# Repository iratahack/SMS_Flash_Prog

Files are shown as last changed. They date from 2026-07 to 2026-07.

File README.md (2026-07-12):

# SEGA Master System Flash Cartridge Programmer

A small USB/Arduino-based programmer and diagnostic tool for Sega Master System ROM cartridges.
It provides a serial-menu interface to identify the cartridge flash, erase and program NOR flash chips,
read or write individual bytes, perform blank checks, and transfer full ROM images using XMODEM-1K.
This repository contains the firmware source (AVR C) used on the programmer hardware and example
host-side workflows for sending/receiving ROM images.

## Hardware

The programmer is an ATmega328p (Arduino Uno / Nano) running at 16 MHz. It accesses the SMS
cartridge slot through the following bus signals:

- **Address bus (A0–A15)**: driven by two cascaded 74HC595 shift registers clocked over the ATmega's SPI peripheral (MOSI=PB3, SCK=PB5, SS=PB2). A high pulse on **RCLK** (PC0) latches the shifted address onto the cartridge bus.
- **Data bus (D0–D7)**: bidirectional GPIO on Arduino pins D2–D9 (PD2–PD7 and PB0–PB1). Direction is toggled per read/write.
- **Control signals**: `_CE` on PC1, `_RD` on PC2, `_WR` on PC3, `_RST` on PC4 (all active low).

KiCad design files for the programmer shield — including schematic, PCB, and Gerbers — live in
[`Arduino_SMS_Cart_Programmer/`](Arduino_SMS_Cart_Programmer/).

### Supported flash chips & Carts

The firmware auto-detects the flash device using the AMD/SST JEDEC ID command sequence and
currently recognises the SST39SF family:

| Manufacturer ID | Device ID | Part | Size  |
| --- | --- | --- | ----- |
| `0xBF` (SST) | `0xB5` | SST39SF010 | 128 KB |
| `0xBF` (SST) | `0xB6` | SST39SF020 | 256 KB |
| `0xBF` (SST) | `0xB7` | SST39SF040 | 512 KB |

The programmer has been tested with the flash cart by [ichigobankai](https://github.com/ichigobankai/SMS_PCB_SLOT1-2_2GAL_DIP)

### Supported mappers

The firmware auto-detects the cartridge mapper at boot and can be switched manually from the menu:

- **SEGA** — standard 16 KB-banked SEGA mapper (bank register at `0xFFFF`).
- **Iratahack** — 3-bit bank + 2-bit game slot (`0xFFFE` / `0xFFFF`) for multi-game carts.

## Building the firmware

Install the AVR toolchain:

```sh
sudo apt-get install gcc-avr avr-libc avrdude
```

Build from the `src/` directory:

```sh
cd src
make                    # compile -> SMSFlasher.bin
make SMSFlasher.bin.hex # Intel HEX output (flashable with avrdude)
make clean              # remove build artifacts
make dis                # disassembly via avr-objdump | less
```

A separate diagnostic firmware that exercises just the 74HC595 address-bus shift registers
lives in [`74hc595/`](74hc595/) and builds with its own `Makefile` in the same way.

Pre-built releases are published on the GitHub Releases page when a `release/vX.Y.Z` tag
is pushed; each release includes `SMSFlasher.bin` and `SMSFlasher.bin.hex`.

## Flashing the firmware to the Arduino

With the Arduino connected as `/dev/ttyUSB0`:

```sh
cd src
make download
```

This runs `avrdude -c arduino -p atmega328p -P /dev/ttyUSB0 -b 115200` against
`SMSFlasher.bin.hex`. Override the port/programmer by editing the `download` target
if your setup differs.

### Arduino COM port setup for WSL

After connecting the programmer via USB to a Windows machine, enter the command below in an
administrator PowerShell to attach the Arduino COM port from Windows to WSL:

```sh
usbipd list # look for USB-SERIAL CH340 (COM4) or similar
usbipd bind --busid <BUSIS> # as administrator
usbipd attach --wsl --busid <BUSID>
```

If the error below is displayed and you already have the latest install of WSL try
`sudo modprobe vhci_hcd` from WSL:

```
usbipd: info: Using WSL distribution 'Ubuntu-22.04' to attach; the device will be available in all WSL 2 distributions.
usbipd: error: WSL kernel is not USBIP capable; update with 'wsl --update'.
```

## Using the programmer

Remember to disconnect the USB connector (power) before connecting or disconnecting a Sega Master System cartridge to
avoid damaging the cartridge or the programmer. When connecting the cartridge, insert the cartridge into the connector
with the front of the cartridge facing the Arduino.

Once the firmware is running, connect a serial terminal to the device at **1,000,000 baud**,
8-N-1, no flow control. The UI uses ANSI colour and Unicode box-drawing characters, so
use a terminal that supports both (e.g. `picocom`, `minicom`). On Windows,
[ExtraPUTTY](https://sourceforge.net/projects/extraputty/) is a good choice and supports
XMODEM-1K for file transfer.

The firmware redraws a full-screen menu on each iteration:

| Key | Action |
| --- | --- |
| `1` | Erase flash (full-chip erase) |
| `2` | Blank check — scan entire flash for `0xFF` |
| `3` | Program flash (receive ROM image over XMODEM-1K) |
| `4` | Checksum — compute CRC32 of flash and compare against last programmed CRC32 |
| `5` | Read a single byte from a hex address |
| `6` | Program a single byte at a hex address |
| `7` | Read ROM — send full flash contents to host over XMODEM-1K |
| `8` | Display SDSC ROM header (if present) |
| `9` | Erase, program (XMODEM-1K), and verify in one step |
| `0` | Toggle between detected mappers (SEGA / Iratahack) |
| `s` | Change ROM/flash size |

The flash size used by operations `2`, `4`, `7`, and `9` is determined by the JEDEC ID
read at each menu redraw, so the programmer adapts automatically to whichever SST39SF
part is installed.

### Transferring ROM images over XMODEM

The firmware uses **XMODEM-1K** (1024-byte packets with CRC-16). The receive path also
accepts classic 128-byte XMODEM packets, but the send path always transmits 1K blocks.
ExtraPUTTY includes XMODEM-1K support for both sending and receiving.

## Repository layout

- [`src/`](src/) — programmer firmware (main target).
- [`74hc595/`](74hc595/) — standalone test firmware that cycles the address-bus shift registers.
- [`Arduino_SMS_Cart_Programmer/`](Arduino_SMS_Cart_Programmer/) — KiCad hardware design files.
- [`.github/workflows/build.yml`](.github/workflows/build.yml) — CI build and release workflow.

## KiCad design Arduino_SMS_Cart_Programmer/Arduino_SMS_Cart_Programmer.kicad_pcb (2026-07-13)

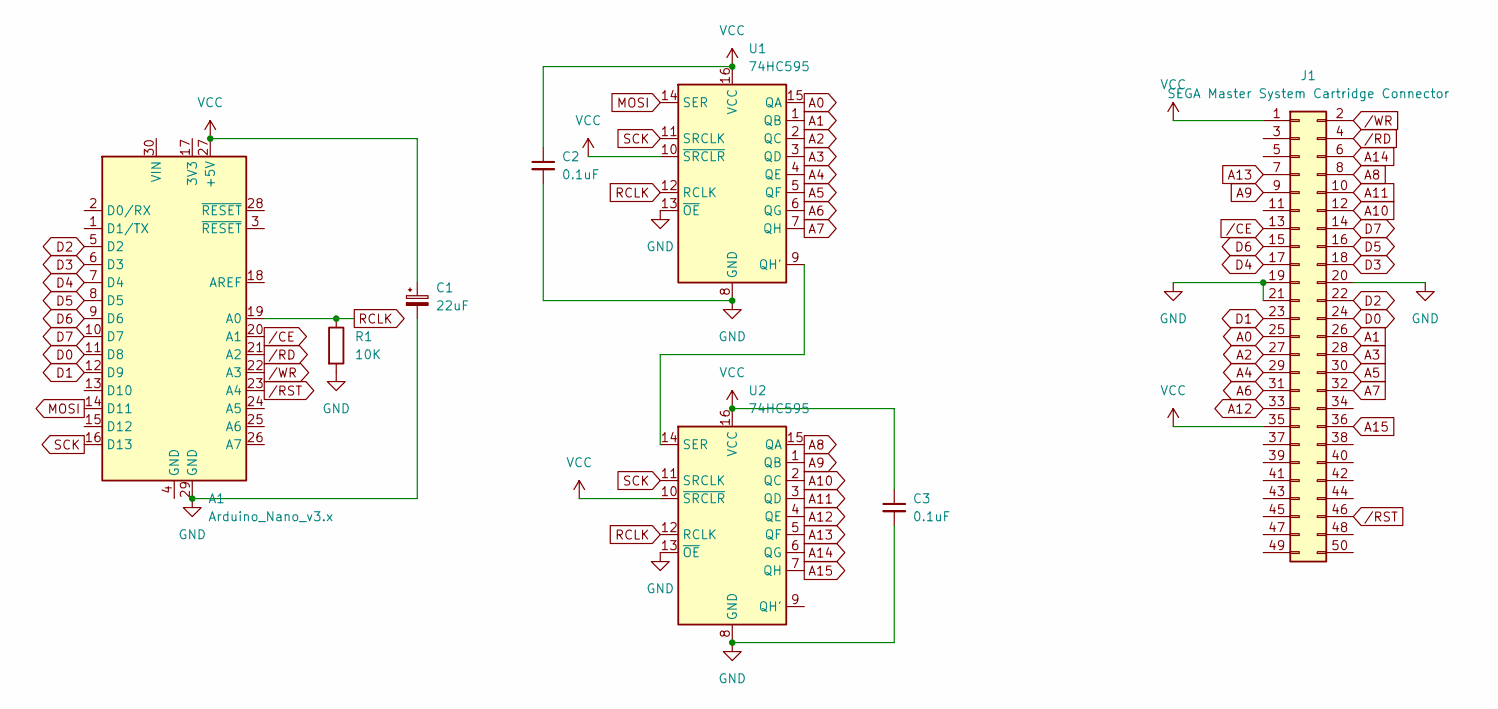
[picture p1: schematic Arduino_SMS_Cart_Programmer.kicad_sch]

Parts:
A1: Arduino_Nano_v3.x; Arduino_Nano
C1: 22uF; CP_Radial_D5.0mm_P2.00mm
C2, C3: 0.1uF; C_Disc_D4.3mm_W1.9mm_P5.00mm
J1: SEGA Master System Cartridge Connector; SEGA_Master_System_Cart_Connector
R1: 10K; R_Axial_DIN0204_L3.6mm_D1.6mm_P7.62mm_Horizontal
U1, U2: 74HC595; DIP-16_W7.62mm

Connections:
A0: J1.25, U1.15 (QA)
A1: J1.26, U1.1 (QB)
A2: J1.27, U1.2 (QC)
A3: J1.28, U1.3 (QD)
A4: J1.29, U1.4 (QE)
A5: J1.30, U1.5 (QF)
A6: J1.31, U1.6 (QG)
A7: J1.32, U1.7 (QH)
A8: J1.8, U2.15 (QA)
A9: J1.9, U2.1 (QB)
A10: J1.12, U2.2 (QC)
A11: J1.10, U2.3 (QD)
A12: J1.33, U2.4 (QE)
A13: J1.7, U2.5 (QF)
A14: J1.6, U2.6 (QG)
A15: J1.36, U2.7 (QH)
D0: A1.11 (D8), J1.24
D1: A1.12 (D9), J1.23
D2: A1.5 (D2), J1.22
D3: A1.6 (D3), J1.18
D4: A1.7 (D4), J1.17
D5: A1.8 (D5), J1.16
D6: A1.9 (D6), J1.15
D7: A1.10 (D7), J1.14
GND: A1.29 (GND), C1.2, C2.2, C3.2, J1.19, J1.20, J1.21, R1.2, U1.8 (GND), U1.13 (~OE), U2.8 (GND), U2.13 (~OE)
MOSI: A1.14 (D11), U1.14 (SER)
unnamed: U1.9 (QH'), U2.14 (SER)
RCLK: A1.19 (A0), R1.1, U1.12 (RCLK), U2.12 (RCLK)
SCK: A1.16 (D13), U1.11 (SRCLK), U2.11 (SRCLK)
VCC: A1.27 (+5V), C1.1, C2.1, C3.1, J1.1, J1.35, U1.10 (~SRCLR), U1.16 (VCC), U2.10 (~SRCLR), U2.16 (VCC)
/CE: A1.20 (A1), J1.13
/RD: A1.21 (A2), J1.4
/RST: A1.23 (A4), J1.46
/WR: A1.22 (A3), J1.2

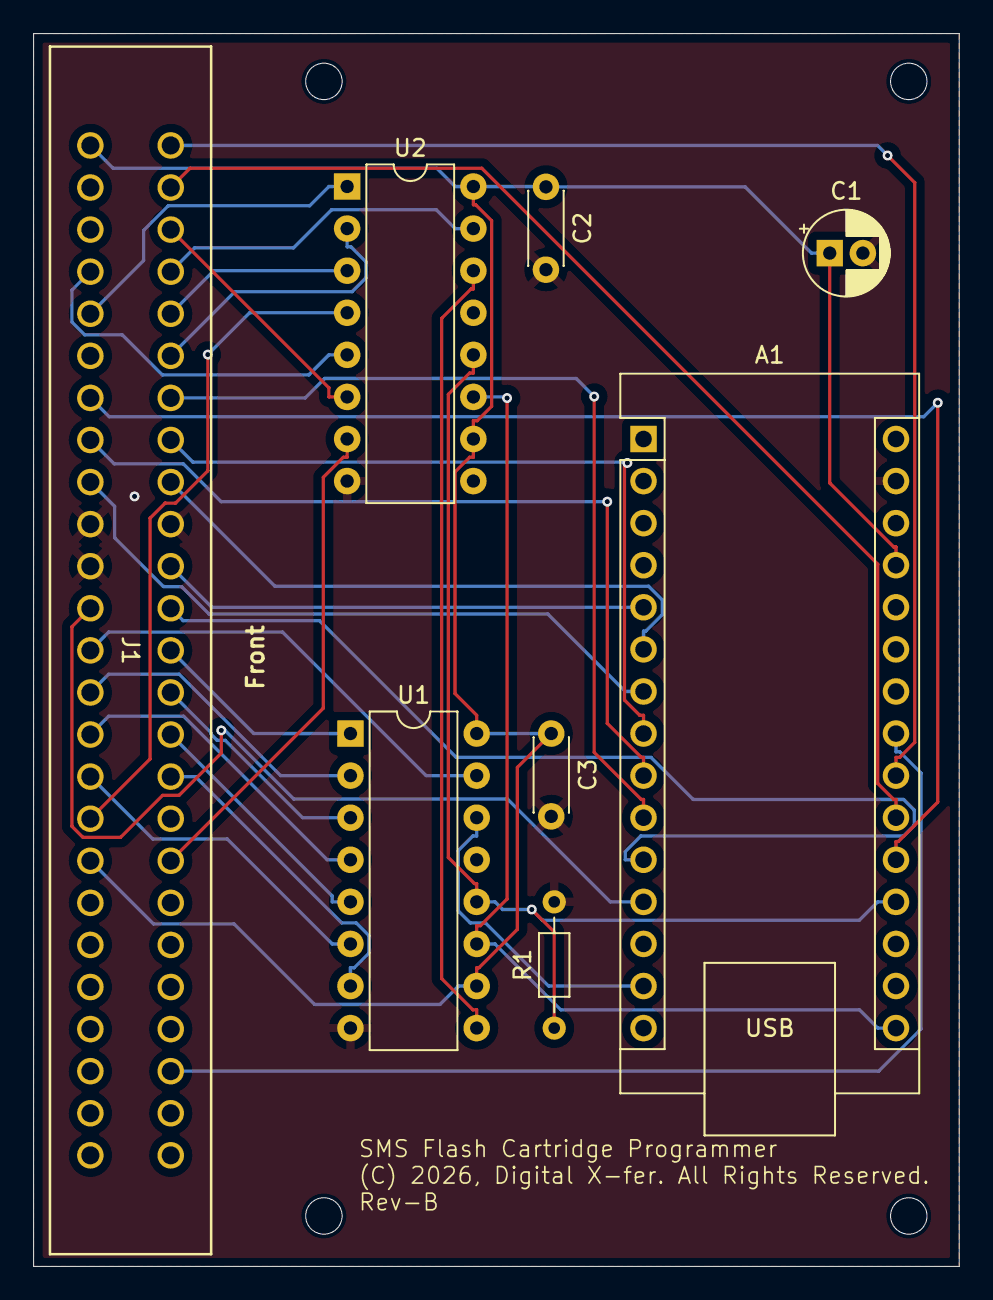
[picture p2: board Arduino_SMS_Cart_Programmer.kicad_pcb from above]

Board: 2 copper layers, 55.9 x 74.4 mm, 12 parts (0 on the bottom side), 34 nets.

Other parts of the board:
REF1, REF2, REF3, REF4: MountingHole_2.2mm_M2

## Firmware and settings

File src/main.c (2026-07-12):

#include <string.h>
#include <util/delay.h>
#include "common.h"
#include "mappers.h"

#define RCLK_PIN PC0
#define _CE_PIN PC1
#define _RD_PIN PC2
#define _WR_PIN PC3
#define _RST_PIN PC4

extern uint32_t XMODEM_ReceiveFile(uint8_t *pBuffer, void (*processBlock)(uint8_t *, uint16_t));
extern uint32_t XMODEM_SendFile(uint8_t *pBuffer, uint32_t length, void (*processBlock)(uint8_t *, uint32_t, uint16_t));
extern void initUART(void);
extern void initTimer(void);
extern void updateCRC32(uint32_t *crc, const uint8_t data);

// XMODEM receive buffer
static uint8_t buffer[1024];
// Address pointer for flash programming
static uint32_t flashAddress;
// Flash size in bytes
static uint32_t flashSize = 0;
// CRC32 of flash
static uint32_t flashCRC32;
// CRC32 of programmed data
static uint32_t progCRC32;
// Current mapper index
static uint8_t mapperIndex;
// Y position for text output
static uint8_t yPos;

/* Helpers to move cursor and clear */
void clear_screen(void)
{
    printf(CSI "2J" CSI "H");
    fflush(stdout);
}
void move_to(int r, int c)
{
    printf(CSI "%d;%dH", r, c);
    fflush(stdout);
}
void hide_cursor(void)
{
    printf(CSI "?25l");
    fflush(stdout);
}
void show_cursor(void)
{
    printf(CSI "?25h");
    fflush(stdout);
}

static void SPI_initMaster(void)
{
    // Set MOSI (PB3), SCK (PB5), SS (PB2) as output
    DDRB |= (_BV(PB3) | _BV(PB5) | _BV(PB2));
    // Set MISO (PB4) as input
    DDRB &= ~(_BV(PB4));

    // Enable SPI, Set as Master, Set clock rate fosc/4
    SPCR = _BV(SPE) | _BV(MSTR);
    // Double speed for fosc/2
    SPSR = _BV(SPI2X);
}

static void SPI_send(uint8_t data)
{
    SPDR = data; // Load data into the buffer
    while (!(SPSR & _BV(SPIF)))
        ; // Wait until transmission complete
}

static void disable_data_pins_pullups(void)
{
    // D2-D7: PD2-PD7
    PORTD &= ~(0b11111100); // Disable pull-ups on PD2-PD7
    // D8-D9: PB0-PB1
    PORTB &= ~(0b00000011); // Disable pull-ups on PB0, PB1
}

static void set_data_pins_output(void)
{
    // D2-D7: PD2-PD7 (6 bits)
    DDRD |= 0b11111100; // Set PD2-PD7 as output
    // D8-D9: PB0-PB1
    DDRB |= 0b00000011; // Set PB0, PB1 as output
}

static void set_data_pins_input(void)
{
    // D2-D7: PD2-PD7
    DDRD &= ~(0b11111100); // Set PD2-PD7 as input
    // D8-D9: PB0-PB1
    DDRB &= ~(0b00000011); // Set PB0, PB1 as input
    disable_data_pins_pullups();
}

/* Inline macro to read D2-D9 (PD2-PD7 and PB0-PB1). Keep the same
   name so existing call sites do not need to change. Wrap operands
   in parentheses to avoid surprises when expanded. */
#define read_data_pins() ((uint8_t)(((PIND) & 0b11111100) | ((PINB) & 0b00000011)))

// Send a 16-bit address via SPI to the shift registers
static void SPI_sendAddress(uint16_t address)
{
    SPI_send((address >> 8) & 0xFF); // Send high byte
    SPI_send(address & 0xFF);        // Send low byte
    PORTC |= _BV(RCLK_PIN);          // Set RCLK high
    PORTC &= ~_BV(RCLK_PIN);         // Set RCLK low
}

void writeCartByte(uint32_t address, uint8_t data)
{
    // Set data pins as output
    set_data_pins_output();

    // Send address
    SPI_sendAddress(address);

    // Write data to data pins
    PORTD = (PORTD & 0b00000011) | (data & 0b11111100); // D2-D7
    PORTB = (PORTB & 0b11111100) | (data & 0b00000011); // D8-D9

    // _CE low
    PORTC &= ~(_BV(_CE_PIN));

    // Pulse WR to write data, min delay is 40nS
    PORTC &= ~(_BV(_WR_PIN));
    PORTC |= _BV(_WR_PIN);

    // _CE high
    PORTC |= _BV(_CE_PIN);
}

uint8_t readRawCartByte(uint32_t address)
{
    uint8_t data;

    // Set data pins to input
    set_data_pins_input();

    // Send address
    SPI_sendAddress(address);
    // _CE low, _RD low
    PORTC &= ~(_BV(_CE_PIN) | _BV(_RD_PIN));

    // Read data from data pins
    // Add nop's to allow data to stabilize
    asm("nop\n"
        "nop\n");
    data = read_data_pins();

    // _CE high, _RD high
    PORTC |= _BV(_RD_PIN) | _BV(_CE_PIN);

    return data;
}

static uint8_t readCartByte(uint32_t address)
{
    uint8_t data;
    uint16_t offset;

    // Select bank/slot and compute offset
    translateAddress(address, &offset);

    // Set data pins to input
    set_data_pins_input();

    // Send address
    SPI_sendAddress(offset);
    // _CE low, _RD low
    PORTC &= ~(_BV(_CE_PIN) | _BV(_RD_PIN));

    // Read data from data pins
    // Add nop's to allow data to stabilize
    asm("nop\n"
        "nop\n");
    data = read_data_pins();

    // _CE high, _RD high
    PORTC |= _BV(_RD_PIN) | _BV(_CE_PIN);

    return data;
}

// Helper function to read a 16-bit pointer from header (file scope)
static uint16_t readHeaderPointer(uint16_t addr)
{
    return readCartByte(addr) | (readCartByte(addr + 1) << 8);
}

static uint8_t bcdToUint8(uint8_t bcd)
{
    return ((bcd >> 4) & 0x0F) * 10 + (bcd & 0x0F);
}

// Helper function to print a null-terminated string from ROM (file scope)
static void printROMString(uint16_t strPtr)
{
    if (strPtr == 0 || strPtr == 0xFFFF)
    {
        printf("(None)");
        return;
    }

    for (uint16_t i = strPtr;; i++)
    {
        uint8_t c = readCartByte(i);
        if (c == 0)
            break;
        if (c < 32)
            continue; // Skip control characters
        printf("%c", c);
    }
}

static uint16_t findSDSCHeader(void)
{
    // Search for SDSC signature in ROM
    // Common locations are 0x7FE0 and near the start of ROM
    const uint16_t searchLocations[] = {0x7FE0, 0x0000};
    const uint16_t searchRanges[] = {0x10, 0x100}; // How far to search from each location

    for (uint8_t loc = 0; loc < sizeof(searchLocations) / sizeof(searchLocations[0]); loc++)
    {
        uint16_t addr = searchLocations[loc];
        for (uint16_t i = 0; i < searchRanges[loc]; i++)
        {
            if (readCartByte(addr + i) == 'S' &&
                readCartByte(addr + i + 1) == 'D' &&
                readCartByte(addr + i + 2) == 'S' &&
                readCartByte(addr + i + 3) == 'C')
            {
                return addr + i;
            }
        }
    }
    return 0; // Return 0 if not found
}

static void displaySDSCHeader(void)
{
    uint16_t signature = findSDSCHeader();
    if (!signature)
    {
        printf(FG_RED "No SDSC ROM signature detected." COLOR_RESET "\n");
        return; // No SDSC header found
    }

    uint16_t headerAddr = signature + 4; // Skip "SDSC" signature
    uint8_t versionMajor = bcdToUint8(readCartByte(headerAddr + 0));
    uint8_t versionMinor = bcdToUint8(readCartByte(headerAddr + 1));

    printf("SDSC Header Information:\n");
    printf("Version: %u.%u\n", versionMajor, versionMinor);

    // Display release date from BCD format (DD MM YY YY)
    uint8_t day = bcdToUint8(readCartByte(headerAddr + 2));
    uint8_t month = bcdToUint8(readCartByte(headerAddr + 3));
    uint8_t yearLow = readCartByte(headerAddr + 4);
    uint8_t yearHigh = readCartByte(headerAddr + 5);

    uint16_t year = (((yearHigh >> 4) & 0x0F) * 1000) +
                    ((yearHigh & 0x0F) * 100) +
                    (((yearLow >> 4) & 0x0F) * 10) +
                    (yearLow & 0x0F);

    printf("Release Date: %04u.%02u.%02u\n", year, month, day);

    // Read all string pointers (they're stored sequentially)
    uint16_t authorPtr = readHeaderPointer(headerAddr + 6);
    uint16_t namePtr = readHeaderPointer(headerAddr + 8);
    uint16_t descPtr = readHeaderPointer(headerAddr + 10);

    // Display all strings using the same format
    printf("Author: ");
    printROMString(authorPtr);
    printf("\nName: ");
    printROMString(namePtr);
    printf("\nDescription: ");
    printROMString(descPtr);
    printf("\n");
}

static uint32_t displayROMHeader(void)
{
    uint32_t size = 0;
    // ROM Header starts at 0x7FF0
    uint16_t headerAddr = 0x7FF0;

    // Check "TMR SEGA" signature first
    uint8_t sig[8];
    for (int i = 0; i < 8; i++)
    {
        sig[i] = readCartByte(headerAddr + i);
    }

    yPos = 3;
    move_to(yPos++, 40);
    printf("Cart Header Info\n");

    // Verify we have the correct signature before displaying header
    if (memcmp(sig, "TMR SEGA", 8))
    {
        printf(FG_RED "No SEGA ROM signature detected." COLOR_RESET);
        return size;
    }

    move_to(yPos++, 40);
    // Display the signature
    printf("ROM Signature: ");
    for (int i = 0; i < 8; i++)
    {
        printf("%c", sig[i]);
    }

    move_to(yPos++, 40);
    // Read product code and version
    printf("Product Code : %02X%02X",
           readCartByte(headerAddr + 0x0C),
           readCartByte(headerAddr + 0x0D));
    move_to(yPos++, 40);
    printf("Version      : %02X", readCartByte(headerAddr + 0x0E));

    // Read ROM size
    uint8_t romSizeCode = readCartByte(headerAddr + 0x0F) & 0x0F;
    move_to(yPos++, 40);
    printf("ROM Size     : ");
    switch (romSizeCode)
    {
    case 0xa:
        printf("8KB (Unused)");
        size = ((uint32_t)8 * (uint32_t)1024); // 8KB
        break;
    case 0xb:
        printf("16KB (Unused)");
        size = ((uint32_t)16 * (uint32_t)1024); // 16KB
        break;
    case 0xc:
        printf("32KB");
        size = ((uint32_t)32 * (uint32_t)1024); // 32KB
        break;
    case 0xd:
        printf("48KB (Unused, buggy)");
        size = ((uint32_t)48 * (uint32_t)1024); // 48KB
        break;
    case 0xe:
        printf("64KB (Rarely used)");
        size = ((uint32_t)64 * (uint32_t)1024); // 64KB
        break;
    case 0xf:
        printf("128KB");
        size = ((uint32_t)128 * (uint32_t)1024); // 128KB
        break;
    case 0x0:
        printf("256KB");
        size = ((uint32_t)256 * (uint32_t)1024); // 256KB
        break;
    case 0x1:
        printf("512KB (Rarely used)");
        size = ((uint32_t)512 * (uint32_t)1024); // 512KB
        break;
    case 0x2:
        printf("1MB (Unused, buggy)");
        size = ((uint32_t)1024 * (uint32_t)1024); // 1MB
        break;
    default:
        printf("Unknown (0x%X)", romSizeCode);
        break;
    }

    // Read region code
    uint8_t region = readCartByte(headerAddr + 0x0F) >> 4;
    move_to(yPos++, 40);
    printf("Region       : ");
    switch (region)
    {
    case 0x3:
        printf("SMS Japan");
        break;
    case 0x4:
        printf("SMS Export");
        break;
    case 0x5:
        printf("Game Gear Japan");
        break;
    case 0x6:
        printf("Game Gear Export");
        break;
    case 0x7:
        printf("Game Gear International");
        break;
    default:
        printf("Unknown (0x%X)", region);
        break;
    }

    // Read checksum
    uint16_t checksum = (readCartByte(headerAddr + 0x0A) << 8) | readCartByte(headerAddr + 0x0B);
    move_to(yPos++, 40);

    return size;
}

// Program a byte to the flash at the specified address
//
// Programming is always performed by selecting the appropriate bank and slot
// presented at offset 0x8000.
static void progCartByte(uint32_t address, uint8_t data)
{

    uint16_t offset;

    // Select bank/slot and compute offset
    translateAddress(address, &offset);

    writeCartByte(0x5555, 0xaa); // Unlock command
    writeCartByte(0x2aaa, 0x55); // Unlock command
    writeCartByte(0x5555, 0xa0); // Write command
    writeCartByte(offset, data); // Write data byte
    _delay_us(10);
}

static void processBlock(uint8_t *block, uint16_t length)
{
    // process the received block (e.g., write to flash)
    // Packets are always 128 bytes long for XMODEM
    for (int i = 0; i < length; i++)
    {
        progCartByte(flashAddress, block[i]);
        updateCRC32(&progCRC32, block[i]);
        flashAddress++;
    }
}

static void getFlashID(void)
{
    uint8_t manufacturerID, deviceID;

    yPos = 3;

    // Send command to read ID
    writeCartByte(0x5555, 0xaa); // Unlock command
    writeCartByte(0x2aaa, 0x55); // Unlock command
    writeCartByte(0x5555, 0x90); // Read ID command

    // Read Manufacturer ID
    manufacturerID = readCartByte(0x0000);
    // Read Device ID
    deviceID = readCartByte(0x0001);

    // Exit ID mode
    writeCartByte(0x0000, 0xF0);

    switch (manufacturerID)
    {
    case 0xBF:
        move_to(yPos++, 3);
        printf("Manufacturer: SST (MCHP)");
        switch (deviceID)
        {
        case 0xB5:
            move_to(yPos++, 3);
            printf(" (SST39SF010)");
            flashSize = ((uint32_t)128 * (uint32_t)1024); // 128KB
            break;
        case 0xB6:
            move_to(yPos++, 3);
            printf(" (SST39SF020)");
            flashSize = ((uint32_t)256 * (uint32_t)1024); // 256KB
            break;
        case 0xB7:
            move_to(yPos++, 3);
            printf(" (SST39SF040)");
            flashSize = ((uint32_t)512 * (uint32_t)1024); // 512KB
            break;
        default:
            move_to(yPos++, 3);
            printf("Device      : Unknown (0x%02X)", deviceID);
            break;
        }
        break;
    default:
        move_to(yPos++, 3);
        printf(FG_RED "No flash device detected." COLOR_RESET);
        move_to(yPos++, 3);
        printf("Auto-detecting ROM size...");
        // Attempt to auto-detect ROM size by looking for at least 8KB of 0xFF at the end of the ROM
        for (uint32_t testSize = (uint32_t)32 * 1024; testSize <= (uint32_t)512 * 1024; testSize *= 2)
        {
            uint8_t hasTrailingFF = 1;
            for (uint32_t offset = testSize - ((uint32_t)8 * 1024); offset < testSize; offset++)
            {
                if (readCartByte(offset) != 0xFF)
                {
                    hasTrailingFF = 0;
                    break;
                }
            }

            if (hasTrailingFF)
            {
                flashSize = testSize;
                move_to(yPos++, 3);
                printf(FG_GREEN "Detected ROM size: %luKB" COLOR_RESET, flashSize / 1024);
                break;
            }
        }
        if (flashSize == 0)
        {
            move_to(yPos++, 3);
            printf(FG_RED "Unable to detect ROM size." COLOR_RESET);
        }

        break;
    }

    move_to(yPos++, 3);
    printf("ROM Size    : %luKB (S to change)", flashSize / 1024);
    move_to(yPos++, 3);
    printf("ROM CRC32   : 0x%08lX", flashCRC32);
    move_to(yPos++, 3);
    printf("Prog. CRC32 : 0x%08lX", progCRC32);
    move_to(yPos++, 3);
    printf("Mapper      : %s", getCurrentMapperName());
}

static void eraseFlash(void)
{
    printf("Erasing flash...\n");
    writeCartByte(0x5555, 0xaa); // Unlock command
    writeCartByte(0x2aaa, 0x55); // Unlock command
    writeCartByte(0x5555, 0x80); // Erase command
    writeCartByte(0x5555, 0xaa); // Unlock command
    writeCartByte(0x2aaa, 0x55); // Unlock command
    writeCartByte(0x5555, 0x10); // Chip erase command
    _delay_ms(100);              // Wait for erase to complete
    printf("Erase complete.\n");
}

static void xmodemProgramFlash(void)
{
    uint32_t downloadedSize;

    printf("Starting XMODEM file receive for programming...\n");
    // Program Flash
    flashAddress = 0;
    progCRC32 = 0xFFFFFFFF;
    downloadedSize = XMODEM_ReceiveFile(buffer, processBlock);
    // Calculate checksum over remaining flash size as downloaded
    // file may be smaller than flash size
    for (uint32_t addr = downloadedSize; addr < flashSize; addr++)
    {
        uint8_t data = readCartByte(addr);
        updateCRC32(&progCRC32, data);
    }
    printf("Programming complete. Programmed CRC32: 0x%08lX\n", progCRC32);
}

static void processSendBlock(uint8_t *block, uint32_t start, uint16_t length)
{
    // process the received block (e.g., write to flash)
    while (length--)
    {
        *block = readCartByte(start++);
        updateCRC32(&flashCRC32, *block);
        block++;
    }
}

static void xmodemReadFlash(void)
{
    uint32_t bytesSent;

    flashCRC32 = 0xFFFFFFFF;
    printf("Starting XMODEM file send for flash read...\n");
    bytesSent = XMODEM_SendFile(buffer, flashSize, processSendBlock);
    printf("Read complete (%lu bytes sent). CRC32: 0x%08lX\n", bytesSent, flashCRC32);
}

static void checksumFlash(void)
{
    printf("Checksuming flash...\n");
    flashCRC32 = 0xFFFFFFFF;
    for (uint32_t addr = 0; addr < flashSize; addr++)
    {
        uint8_t data = readCartByte(addr);
        updateCRC32(&flashCRC32, data);
    }
    if (flashCRC32 == progCRC32)
    {
        printf(FG_GREEN "Flash verification successful. CRC32 matches: 0x%08lX" COLOR_RESET "\n", flashCRC32);
    }
    else
    {
        printf(FG_RED "Flash verification failed. Expected CRC32: 0x%08lX, Read CRC32: 0x%08lX" COLOR_RESET "\n", progCRC32, flashCRC32);
    }
}
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
int main(void)
{
    uint8_t input;

    // Configure control pins as output and set them high
    DDRC = _BV(RCLK_PIN) | _BV(_CE_PIN) | _BV(_RD_PIN) | _BV(_WR_PIN) | _BV(_RST_PIN); // Set RCLK_PIN, _CE_PIN, _RD_PIN, _WR_PIN as output
    PORTC = _BV(_CE_PIN) | _BV(_RD_PIN) | _BV(_WR_PIN) | _BV(_RST_PIN);                // Set _CE_PIN, _RD_PIN, _WR_PIN high, _RST_PIN low
    _delay_ms(10); // Wait for reset to settle
    PORTC = PORTC | _BV(_RST_PIN); // Set _RST_PIN high

    initUART();
    initTimer();
    SPI_initMaster();
    set_data_pins_input();

    mapperIndex = detectMapper();
    setMapper(&mappers[mapperIndex]);

    for (;;)
    {
        hide_cursor();
        repaint_ui(1, 1, 80, 19);

        getFlashID();

        displayROMHeader();

        yPos = 9;
        move_to(yPos++, 1);
        printf("%S", BOX_LH);
        for (int i = 0; i < 78; i++)
            printf("%S", BOX_H);
        printf("%S", BOX_RH);

        move_to(yPos++, 3);
        printf("1 ........ Erase");
        move_to(yPos++, 3);
        printf("2 ........ Blank Check");
        move_to(yPos++, 3);
        printf("3 ........ Program (XMODEM-1K download)");
        move_to(yPos++, 3);
        printf("4 ........ Checksum");
        move_to(yPos++, 3);
        printf("5 ........ Read Byte");
        move_to(yPos++, 3);
        printf("6 ........ Program Byte");
        move_to(yPos++, 3);
        printf("7 ........ Read ROM (XMODEM-1K upload)");
        move_to(yPos++, 3);
        printf("8 ........ Display SDSC ROM Header");
        move_to(yPos++, 3);
        printf("9 ........ Erase, Program (XMODEM-1K download), and Verify");
        move_to(yPos++, 3);
        printf("0 ........ Change Mapper (Current: %s)", getCurrentMapperName());
        move_to(yPos++, 3);
        printf("Select an option: ");

        input = getchar();

        clear_screen();
        show_cursor();

        switch (input)
        {
        case '1':
            eraseFlash();
            printf("Press any key to continue...\n");
            getchar();
            break;
        case '2':
        {
            uint32_t addr;
            // Blank Check Flash
            printf("Performing blank check...\n");
            for (addr = 0; addr < flashSize; addr++)
            {
                if (readCartByte(addr) != 0xFF)
                {
                    printf(FG_RED "Flash is NOT blank. First non-blank byte at address 0x%06lX: 0x%02X" COLOR_RESET "\n", addr, readCartByte(addr));
                    break;
                }
            }
            if (addr == flashSize)
            {
                printf(FG_GREEN "Blank check successful." COLOR_RESET "\n");
            }
            printf("Press any key to continue...\n");
            getchar();
        }
        break;
        case '3':
            xmodemProgramFlash();
            printf("Press any key to continue...\n");
            getchar();
            break;
        case '4':
            // Checksum Flash
            checksumFlash();
            printf("Press any key to continue...\n");
            getchar();
            break;
        case '5':
        {
            uint32_t address;
            printf("Enter address to read (hex): 0x");
            scanf("%lx", &address);
            uint8_t data = readCartByte(address);
            printf("Data at address 0x%06lX: 0x%02X\n", address, data);
            printf("Press any key to continue...\n");
            getchar(); // Consume newline
            getchar(); // Wait for key
        }
        break;
        case '6':
        {
            uint32_t address;
            uint8_t data;
            printf("Enter address to write (hex): 0x");
            scanf("%lx", &address);
            printf("Enter data to write (hex): 0x");
            scanf("%hhx", &data);
            progCartByte(address, data);
            printf("Press any key to continue...\n");
            getchar(); // Consume newline
            getchar(); // Wait for key
        }
        break;
        case '7':
            // Read Flash via XMODEM
            xmodemReadFlash();
            printf("Press any key to continue...\n");
            getchar();
            break;
        case '8':
            displaySDSCHeader();
            printf("Press any key to continue...\n");
            getchar();
            break;
        case '9':
            eraseFlash();
            xmodemProgramFlash();
            checksumFlash();
            printf("Press any key to continue...\n");
            getchar();
            break;
        case '0':
            mapperIndex = (mapperIndex + 1) % (sizeof(mappers) / sizeof(mappers[0]));
            setMapper(&mappers[mapperIndex]);
            break;
        case 's':
        case 'S':
            printf("Enter new ROM size in KB: ");
            uint32_t newSizeKB;
            scanf("%lu", &newSizeKB);
            flashSize = newSizeKB * 1024;
            printf("ROM size changed to %luKB.\n", newSizeKB);
            printf("Press any key to continue...\n");
            getchar(); // Consume newline
            getchar(); // Wait for key
            break;
        default:
            break;
        }
    }
}

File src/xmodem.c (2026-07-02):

/* ----------------------------------------------------------------------------
 *         ATMEL Microcontroller Software Support
 * ----------------------------------------------------------------------------
 * Copyright (c) 2010, Atmel Corporation

 * All rights reserved.
 *
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
 * Atmel's name may not be used to endorse or promote products derived from
 * this software without specific prior written permission.
 *
 * DISCLAIMER: THIS SOFTWARE IS PROVIDED BY ATMEL "AS IS" AND ANY EXPRESS OR
 * IMPLIED WARRANTIES, INCLUDING, BUT NOT LIMITED TO, THE IMPLIED WARRANTIES OF
 * MERCHANTABILITY, FITNESS FOR A PARTICULAR PURPOSE AND NON-INFRINGEMENT ARE
 * DISCLAIMED. IN NO EVENT SHALL ATMEL BE LIABLE FOR ANY DIRECT, INDIRECT,
 * INCIDENTAL, SPECIAL, EXEMPLARY, OR CONSEQUENTIAL DAMAGES (INCLUDING, BUT NOT
 * LIMITED TO, PROCUREMENT OF SUBSTITUTE GOODS OR SERVICES; LOSS OF USE, DATA,
 * OR PROFITS; OR BUSINESS INTERRUPTION) HOWEVER CAUSED AND ON ANY THEORY OF
 * LIABILITY, WHETHER IN CONTRACT, STRICT LIABILITY, OR TORT (INCLUDING
 * NEGLIGENCE OR OTHERWISE) ARISING IN ANY WAY OUT OF THE USE OF THIS SOFTWARE,
 * EVEN IF ADVISED OF THE POSSIBILITY OF SUCH DAMAGE.
 * ----------------------------------------------------------------------------
 */

/**
 * \file
 *
 * Implementation of XMODEM transfer protocols
 *
 */

/*----------------------------------------------------------------------------
 *        Headers
 *----------------------------------------------------------------------------*/
#include "common.h"

extern volatile uint16_t ticks;

/*----------------------------------------------------------------------------
 *        Local definitions
 *----------------------------------------------------------------------------*/
/** The definitions are followed by the X/Ymodem protocol */
#define XMDM_SOH 0x01 /**< Start of heading */
#define XMDM_STX 0x02 /**< Start of text */
#define XMDM_EOT 0x04 /**< End of text */
#define XMDM_ACK 0x06 /**< Acknowledge  */
#define XMDM_NAK 0x15 /**< negative acknowledge */
#define XMDM_CAN 0x18 /**< Cancel */
#define XMDM_ESC 0x1b /**< Escape */

#define CRC16POLY 0x1021 /**< CRC 16 polynom */

#define UART_IsRxReady() (UCSR0A & (1 << RXC0))

/*----------------------------------------------------------------------------
 *        Local variables
 *----------------------------------------------------------------------------*/
/** Xmodem transfer error indicator */
static uint8_t lastGoodSeq;
static const uint16_t crc16_table[256] PROGMEM = {
    0x0000, 0x1021, 0x2042, 0x3063, 0x4084, 0x50A5, 0x60C6, 0x70E7,
    0x8108, 0x9129, 0xA14A, 0xB16B, 0xC18C, 0xD1AD, 0xE1CE, 0xF1EF,
    0x1231, 0x0210, 0x3273, 0x2252, 0x52B5, 0x4294, 0x72F7, 0x62D6,
    0x9339, 0x8318, 0xB37B, 0xA35A, 0xD3BD, 0xC39C, 0xF3FF, 0xE3DE,
    0x2462, 0x3443, 0x0420, 0x1401, 0x64E6, 0x74C7, 0x44A4, 0x5485,
    0xA56A, 0xB54B, 0x8528, 0x9509, 0xE5EE, 0xF5CF, 0xC5AC, 0xD58D,
    0x3653, 0x2672, 0x1611, 0x0630, 0x76D7, 0x66F6, 0x5695, 0x46B4,
    0xB75B, 0xA77A, 0x9719, 0x8738, 0xF7DF, 0xE7FE, 0xD79D, 0xC7BC,
    0x48C4, 0x58E5, 0x6886, 0x78A7, 0x0840, 0x1861, 0x2802, 0x3823,
    0xC9CC, 0xD9ED, 0xE98E, 0xF9AF, 0x8948, 0x9969, 0xA90A, 0xB92B,
    0x5AF5, 0x4AD4, 0x7AB7, 0x6A96, 0x1A71, 0x0A50, 0x3A33, 0x2A12,
    0xDBFD, 0xCBDC, 0xFBBF, 0xEB9E, 0x9B79, 0x8B58, 0xBB3B, 0xAB1A,
    0x6CA6, 0x7C87, 0x4CE4, 0x5CC5, 0x2C22, 0x3C03, 0x0C60, 0x1C41,
    0xEDAE, 0xFD8F, 0xCDEC, 0xDDCD, 0xAD2A, 0xBD0B, 0x8D68, 0x9D49,
    0x7E97, 0x6EB6, 0x5ED5, 0x4EF4, 0x3E13, 0x2E32, 0x1E51, 0x0E70,
    0xFF9F, 0xEFBE, 0xDFDD, 0xCFFC, 0xBF1B, 0xAF3A, 0x9F59, 0x8F78,
    0x9188, 0x81A9, 0xB1CA, 0xA1EB, 0xD10C, 0xC12D, 0xF14E, 0xE16F,
    0x1080, 0x00A1, 0x30C2, 0x20E3, 0x5004, 0x4025, 0x7046, 0x6067,
    0x83B9, 0x9398, 0xA3FB, 0xB3DA, 0xC33D, 0xD31C, 0xE37F, 0xF35E,
    0x02B1, 0x1290, 0x22F3, 0x32D2, 0x4235, 0x5214, 0x6277, 0x7256,
    0xB5EA, 0xA5CB, 0x95A8, 0x8589, 0xF56E, 0xE54F, 0xD52C, 0xC50D,
    0x34E2, 0x24C3, 0x14A0, 0x0481, 0x7466, 0x6447, 0x5424, 0x4405,
    0xA7DB, 0xB7FA, 0x8799, 0x97B8, 0xE75F, 0xF77E, 0xC71D, 0xD73C,
    0x26D3, 0x36F2, 0x0691, 0x16B0, 0x6657, 0x7676, 0x4615, 0x5634,
    0xD94C, 0xC96D, 0xF90E, 0xE92F, 0x99C8, 0x89E9, 0xB98A, 0xA9AB,
    0x5844, 0x4865, 0x7806, 0x6827, 0x18C0, 0x08E1, 0x3882, 0x28A3,
    0xCB7D, 0xDB5C, 0xEB3F, 0xFB1E, 0x8BF9, 0x9BD8, 0xABBB, 0xBB9A,
    0x4A75, 0x5A54, 0x6A37, 0x7A16, 0x0AF1, 0x1AD0, 0x2AB3, 0x3A92,
    0xFD2E, 0xED0F, 0xDD6C, 0xCD4D, 0xBDAA, 0xAD8B, 0x9DE8, 0x8DC9,
    0x7C26, 0x6C07, 0x5C64, 0x4C45, 0x3CA2, 0x2C83, 0x1CE0, 0x0CC1,
    0xEF1F, 0xFF3E, 0xCF5D, 0xDF7C, 0xAF9B, 0xBFBA, 0x8FD9, 0x9FF8,
    0x6E17, 0x7E36, 0x4E55, 0x5E74, 0x2E93, 0x3EB2, 0x0ED1, 0x1EF0
};

/*----------------------------------------------------------------------------
 *        Local functions
 *----------------------------------------------------------------------------*/
/**
 * \brief Transmit the character through xmodem protocol.
 *
 * \param c  Character to be transmitted.
 */
static void XMODEM_PutChar(uint8_t c)
{
    while (!(UCSR0A & _BV(UDRE0)))
        ; /* Wait for empty transmit buffer*/
    UDR0 = c;
}

/**
 * \brief Get the character through xmodem protocol.
 *
 * \return The character received
 */
static uint8_t XMODEM_GetChar(void)
{
    while (!(UCSR0A & (1 << RXC0)))
        ;
    return (UDR0);
}

/**
 * \brief Get bytes through xmodem protocol.
 *
 * \param pData  Pointer to the data buffer.
 * \param length Length of data expected.
 * \return Calculated CRC value.
 */
static uint16_t XMODEM_Getbytes(uint8_t *pData, uint32_t length)
{
    uint16_t crc = 0;

    while (length--)
    {
        *pData = XMODEM_GetChar();
        crc = (crc<<8) ^ pgm_read_word_near(crc16_table + (((crc >> 8) ^ *pData) & 0xff));
        pData++;
    }

    return (crc);
}
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

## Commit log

2025-10-21 Initial checkin.
    [Arduino_SMS_Cart_Programmer-B_Cu.gbr, Arduino_SMS_Cart_Programmer-B_Mask.gbr, Arduino_SMS_Cart_Programmer-B_Silkscreen.gbr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]
2025-10-22 Add CRC32 calculation and XMODEM protocol enhancements
    - Implemented CRC32 table and update function in CRC32.c.
    - Enhanced main.c with flash programming features and improved user interface.
    - Modified timer.c for better tick management.
    - Adjusted UART baud rate in uart.c for higher speed.
    - Refined xmodem.c for improved data handling and error checking.
    [main.c, uart.c, xmodem.c]
2025-10-23 Moved const strings from printf to flash memory.
2025-11-02 Added dummy read to allow data to stabilize.
    [main.c]
2025-11-05 Highlight checksum pass/fail text.
    [main.c]
2025-11-05 Update README.md to enhance documentation on Arduino COM port setup and menu options
2025-11-06 Speed optimizations by only updating slot and bank when needed.
2025-11-27 Enhance error and status messages with ANSI color coding for improved visibility
    [main.c]
2025-12-04 SPI test program for 74hc595 shift register.
2026-02-28 Refactor: improve documentation, code quality, and add CI/CD pipeline
    Changes:
    - Create GitHub Copilot workspace instructions
    - Simplify README with hardware interface details
    - Fix critical issue: buffer type int8_t -> uint8_t
    - Optimize RAM: box drawing in PROGMEM via defines
    - Rename mapper: Multi-game -> Iratahack
    - Update copyright year 2025 -> 2026
    - Add GitHub Actions build and release workflow
    [main.c]
2026-07-02 Updated to display SDSC version correctly.
    [main.c]
2026-07-12 Add reset pin definition and modify ROM header display to return size; update mapper initialization for RAM and slot settings. Allow setting actual ROM size.
2026-07-12 Added cart reset line connection.
    [Arduino_SMS_Cart_Programmer-B_Cu.gbr, Arduino_SMS_Cart_Programmer-B_Mask.gbr, Arduino_SMS_Cart_Programmer-B_Silkscreen.gbr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]
2026-07-12 Added revision to PCB silkscreen.
    [Arduino_SMS_Cart_Programmer-B_Cu.gbr, Arduino_SMS_Cart_Programmer-B_Mask.gbr, Arduino_SMS_Cart_Programmer-B_Silkscreen.gbr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]
2026-07-12 Added mounting holes and lable to front of cart connector.
    [Arduino_SMS_Cart_Programmer-B_Cu.gbr, Arduino_SMS_Cart_Programmer-B_Mask.gbr, Arduino_SMS_Cart_Programmer-B_Silkscreen.gbr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]
2026-07-13 Cleaned up RevB PCB.
    [Arduino_SMS_Cart_Programmer-B_Cu.gbr, Arduino_SMS_Cart_Programmer-B_Mask.gbr, Arduino_SMS_Cart_Programmer-B_Silkscreen.gbr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]

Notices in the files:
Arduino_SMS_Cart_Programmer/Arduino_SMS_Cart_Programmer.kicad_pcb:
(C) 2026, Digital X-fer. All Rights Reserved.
